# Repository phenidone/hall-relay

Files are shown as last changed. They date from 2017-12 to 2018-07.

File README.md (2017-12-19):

# hall-relay

This is a PCB design for a hall-effect sensor with normally-closed, high-current open-drain output.

The intended purpose is to directly control a low-voltage DC load, e.g. cupboard lighting
or it can be integrated with an alarm or building-management system as a door/window sensor.

The open-drain output is active when a magnetic field is not present, i.e. when the door is open and the magnet is away from this sensor.

## Power Supply

This relay will operate between 5V and 24V DC nominal; the absolute-maximum voltage rating is 28V.  It is not reverse-polarity protected.

It has an open-drain output capable of driving up to 1A into an inductive load (relay or solenoid)
or up to 2A into simple (LED tape) loads.

## Magnet

To shut off the relay, align a magnet pole with the OSHW (gear) logo on the non-component side of the board.

The sensor is omnipolar so it doesn't matter which way the magnet is installed.

## Installation

This sensor should be placed in a door frame with the non-component side of the board exposed to the moving item (door?) that
is to be detected.  Two screw-holes are provided for fixing, and these screws can double as magnetic latching/anchor points.

The PCB assembly must be potted in epoxy after assembly to protect it from moisture.

Connect a 5V-24V isolated plugpack to the + and - terminals.

Connect a DC load (expecting the same voltage as supplied by the plugpack) between the + and OD terminals

## License

This hardware design is (C) 2017 William Brodie-Tyrrell and is licensed under the CERN OHL; see cern_ohl_v_1_2.pdf

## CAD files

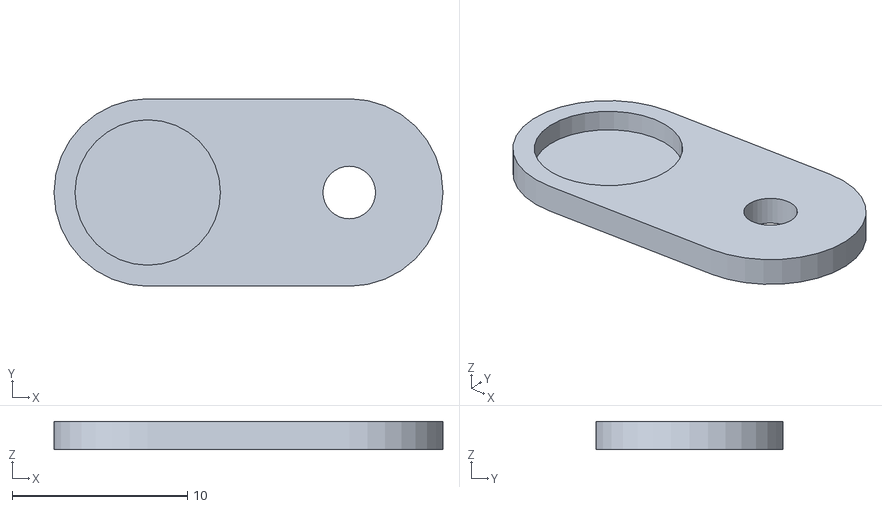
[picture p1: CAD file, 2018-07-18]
housing/magnet-flat.stl
22.2 x 10.7 x 1.60

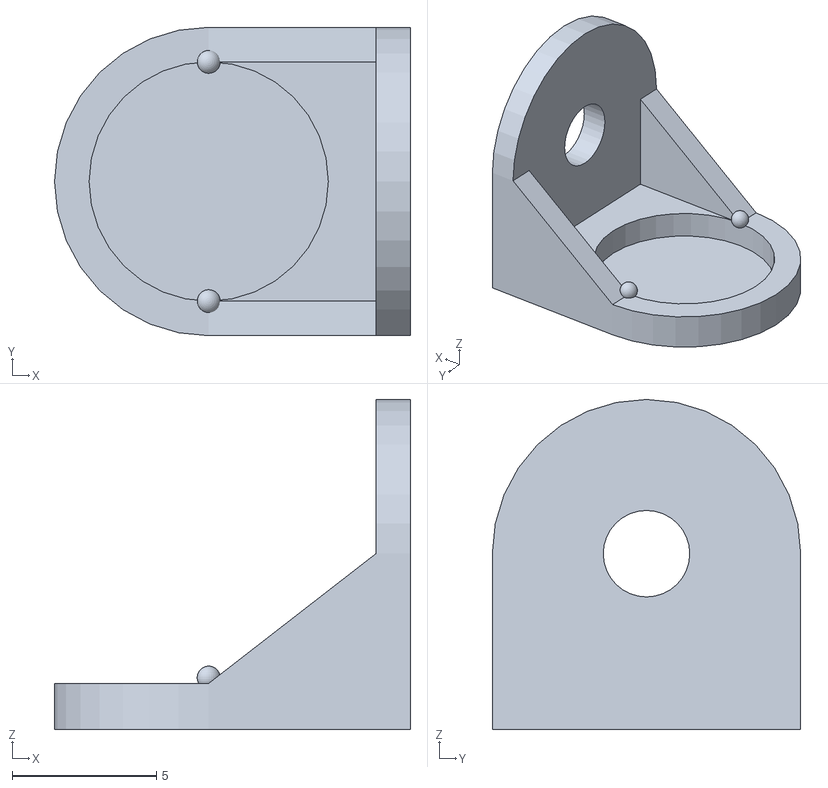
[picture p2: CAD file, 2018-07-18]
housing/magnet-90deg.stl
12.4 x 10.7 x 11.4

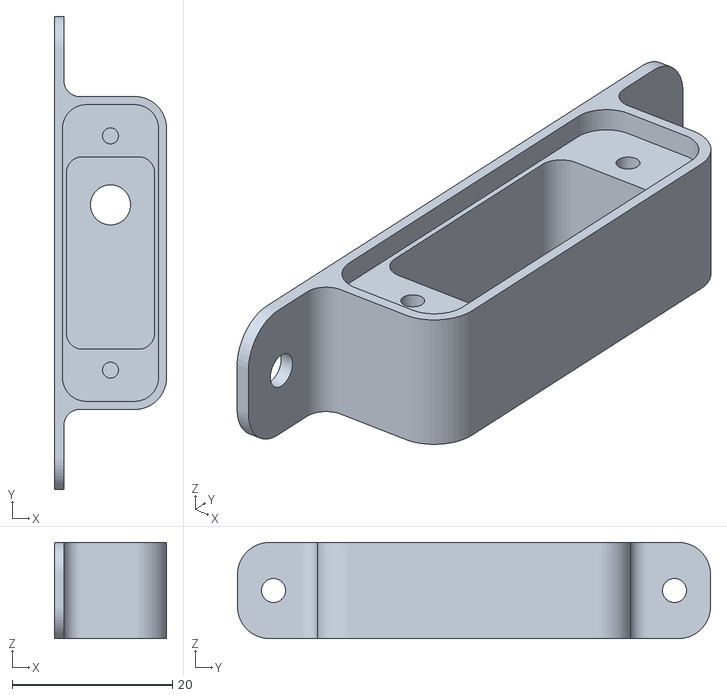
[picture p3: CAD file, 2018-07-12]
housing/hall-90deg.stl
14.0 x 59.0 x 12.0

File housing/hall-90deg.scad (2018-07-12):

// with thanks to HAD...
module cylinders(points, radius, height)
{
    for (p=points){
        translate(p) cylinder(r=radius, h=height, center=true);
    }
}

// box, rounded in 2 dimensions but flat top+bottom
// is centred
module round2box(size, radius)
{
    points=[ [-size[0]/2+radius, -size[1]/2+radius, 0],
             [-size[0]/2+radius, size[1]/2-radius, 0],
             [size[0]/2-radius, -size[1]/2+radius, 0],
             [size[0]/2-radius, size[1]/2-radius, 0]];
    
    hull() cylinders(points, radius, size[2]);
}

// bracket dimensions
epsilon=0.05;
pcbrad=3;
fillet=2;
wall=1;
tablen=10;
tabthick=1.2;
outerrad=pcbrad+wall;
pcb=[12, 37, 2];  // PCB space
clearance=[11, 24, 9];  // component-area
outer=[pcb[0]+2*wall, pcb[1]+2*wall, clearance[2]+3];  // casing size
tabs=[outer[2], outer[1]+2*tablen, outer[0]/2];
tabfillet=[outer[0], tablen+2*outerrad, outer[2]+1];
screwpilot=2;
screw=3;
screwspace=1.15*25.4;
cable=5;

$fn=50;
$fs=epsilon;

// assemble, upside-down for ease of FDM printing
rotate(a=[0, 180, 0]) difference()
{
    union()
    {
        // datum: centre of bottom face
        translate([0, 0, outer[2]/2])
            // the main casing
            round2box([outer[0], outer[1]+epsilon, outer[2]], outerrad);

        // side tabs - overly thick to make room for fillet
        translate([outer[0]/2-tabs[2]/2, 0, outer[2]/2]) rotate(a=[0, 90, 0])
            round2box(tabs, outerrad);
    }

    // space for the PCBA
    translate([0, 0, -epsilon])
    {
        // datum: bottom centre of the PCB
        
        // pcb space
        translate([0, 0, pcb[2]/2])
            round2box(pcb, pcbrad);

        // component-area clearance
        translate([0, 0, clearance[2]/2+pcb[2]-epsilon])
            // cube(clearance, true);
            round2box(clearance, fillet);
        
        // cable clearance
        translate([0, clearance[1]/4, outer[2]/2])
            cylinder(d=cable, h=outer[2]+1, center=true);
        
        // PCB-screw pilot holes
        translate([0, 0, outer[2]/2-1])
            cylinders([[0, screwspace/2, 0], [0, -screwspace/2, 0]], screwpilot/2, outer[2]);

        
    }

    // fillets from backs of end tabs
    translate([-tabthick, -(tabfillet[1]+outer[1])/2, tabfillet[2]/2-epsilon])
            round2box(tabfillet, fillet);
    translate([-tabthick, (tabfillet[1]+outer[1])/2, tabfillet[2]/2-epsilon])
            round2box(tabfillet, fillet);
    
    // screw clearance holes in tabs
    translate([outer[0]/2, 0, outer[2]/2]) rotate(a=[0, 90, 0])
        cylinders([[0, (outer[1]+tablen+1)/2, 0], [0, -(outer[1]+tablen+1)/2, 0]], screw/2, outer[0]/2);
}

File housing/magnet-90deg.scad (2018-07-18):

// a 90-degree bracket to hold a cylindrical magnet
// the magnet is on the INSIDE of the bracket, which helps with printing and also
// means it's not visible from the direction the magnet would normally be looked at from

// this version has tiny press-retaining tabs so no magnet glue is required.

mag_diam=8.3;
mag_thick=1.2;
mag_ctr=7;
tab_thick=1.2;
skin=0.4;
wall=tab_thick;
screw=3;
screw_ctr=4.5;
wall_ctr=screw_head;

// total width of the bracket
width=mag_diam+2*wall;

epsilon=1e-2;
$fn=32;

// flip part on its back for easy FDM printing
rotate(a=[0, -90, 0]) union() {

    // magnet-holding vertical thing
    rotate(a=[0, -90, 0]){
        difference(){
            union(){
                translate([mag_ctr, 0, 0]) cylinder(d=width, h=mag_thick+skin, center=false);
                translate([0, -width/2, 0]) cube([mag_ctr, width, mag_thick+skin], center=false);
            }

            translate([mag_ctr, 0, -epsilon]) cylinder(d=mag_diam, h=mag_thick, center=false);
        }
        
        // retaining tabs
        for(y=[mag_diam/2, -mag_diam/2]){
            translate([mag_ctr, y, 0]) {
                translate([0, 0, -0.2]) sphere(d=0.8);
                // rotate(a=[45, 0, 0]) cube(0.8, center=true);
            }
        }

    }

    // screw-down tab
    difference(){
        union(){
            translate([screw_ctr, 0, 0]) cylinder(d=width, h=tab_thick, center=false);
            translate([0, -width/2, 0]) cube([screw_ctr, width, tab_thick], center=false);
        }

        translate([screw_ctr, 0, -epsilon]) cylinder(d=screw, h=tab_thick+1, center=false);
    }
    
    // bracing
    for(y=[-width/2, width/2-wall]){
        hull(){
            translate([-1, y, tab_thick-1]) cube([screw_ctr+1, wall, 1], center=false);
            translate([-1, y, 1]) cube([1, wall, mag_ctr-1 /*+0.2*/], center=false);
        }
    }
}

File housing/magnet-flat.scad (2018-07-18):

// a flat bracket to hold a cylindrical magnet
// the magnet is on the INSIDE of the bracket, which
// means it's not visible from the direction the bracket would normally be looked at from

// there are optional tiny retaining tabs

mag_diam=8.3;
mag_thick=1.2;
mag_ctr=7;
skin=0.4;
wall=1.2;
screw=3;
screw_ctr=4.5;
tabs=false;

// total width of the bracket
width=mag_diam+2*wall;

epsilon=1e-2;
$fn=32;

// flip part on its back for easy FDM printing
rotate(a=[0, 180, 0]){
    difference(){
        hull(){
            translate([mag_ctr, 0, 0]) cylinder(d=width, h=mag_thick+skin, center=false);
            translate([-screw_ctr, 0, 0]) cylinder(d=width, h=mag_thick+skin, center=false);
        }

        // magnet hole
        translate([mag_ctr, 0, -epsilon]) cylinder(d=mag_diam, h=mag_thick, center=false);

        // screw hole
        translate([-screw_ctr, 0, -epsilon]) cylinder(d=screw, h=(mag_thick+skin+1), center=false);
    }

    if(tabs){
        // retaining tabs
        for(y=[mag_diam/2, -mag_diam/2]){
            translate([mag_ctr, y, 0]) {
                translate([0, 0, -0.2]) sphere(d=0.8);
            }
        }
    }
    
}

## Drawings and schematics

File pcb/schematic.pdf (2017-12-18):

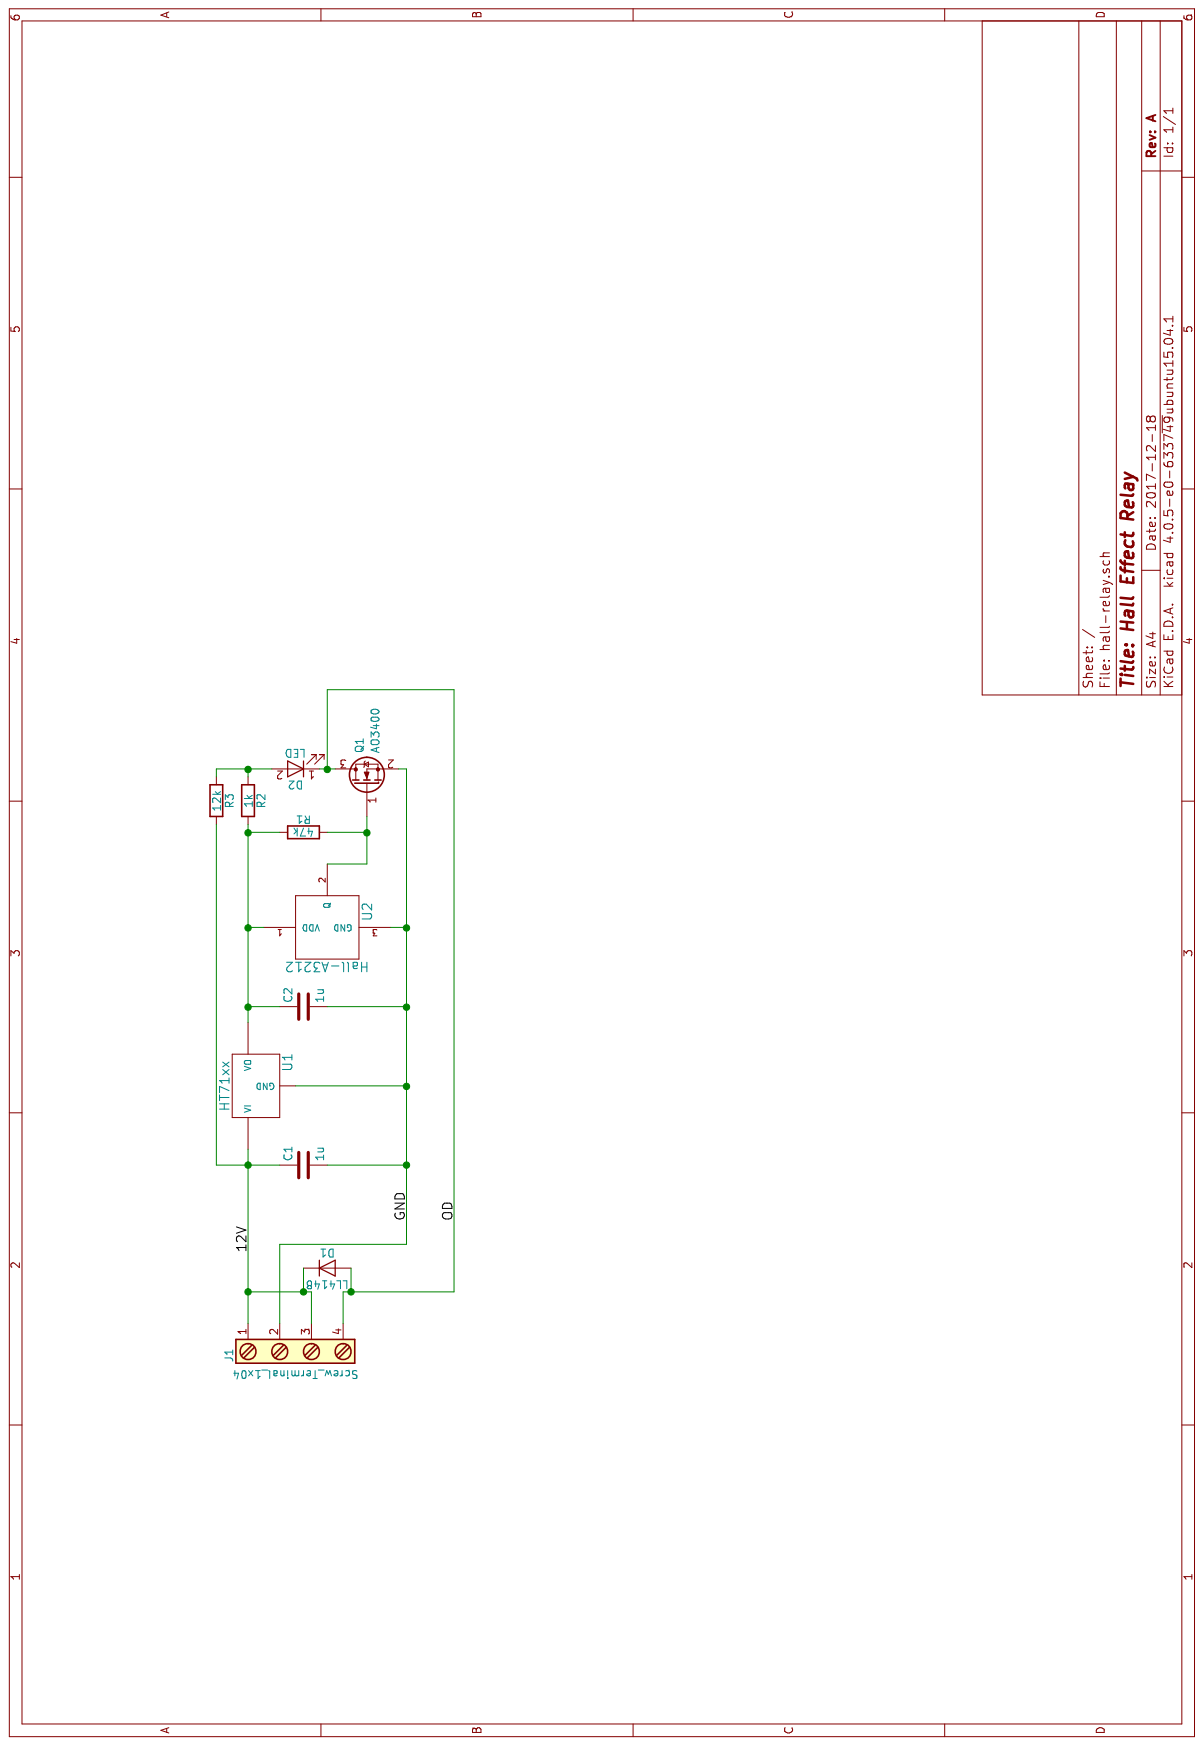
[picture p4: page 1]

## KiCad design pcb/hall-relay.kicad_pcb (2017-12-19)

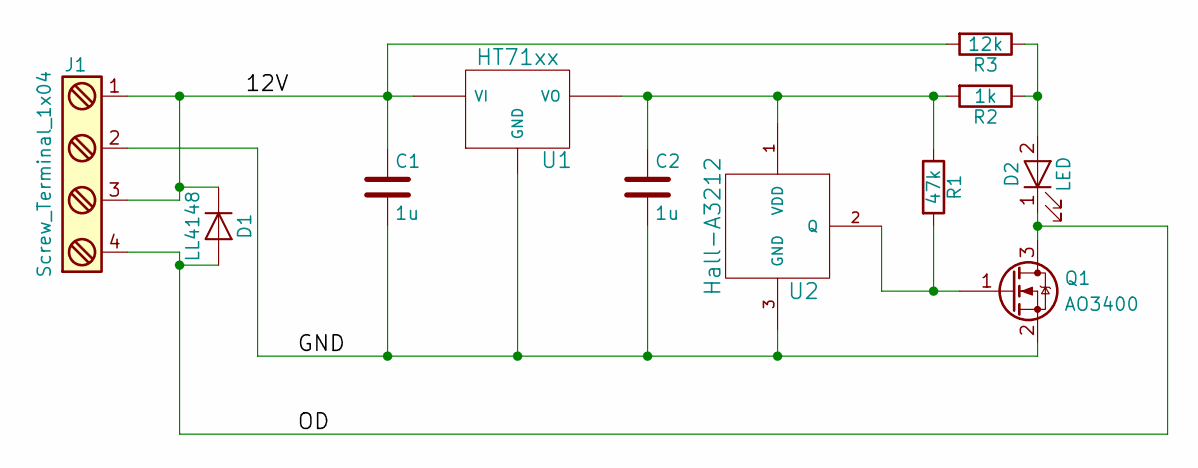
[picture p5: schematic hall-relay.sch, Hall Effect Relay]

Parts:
C1, C2: 1u; C_0805
D1: LL4148; D_MiniMELF
D2: LED; LED_0805
J1: Screw_Terminal_1x04; TerminalBlock_Phoenix_MPT-2.54mm_4pol
Q1: AO3400; SOT-23
R1: 47k; R_0805
R2: 1k; R_0805
R3: 12k; R_0805
U1: HT71xx; SOT-89-3
U2: Hall-A3212; SOT-23

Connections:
/12V: C1.1, D1.1 (K), J1.1, J1.3, R3.2, U1.2 (VI)
/GND: C1.2, C2.2, J1.2, Q1.2 (S), U1.1 (GND), U2.3 (GND)
/OD: D1.2 (A), D2.1 (K), J1.4, Q1.3 (D)
unnamed: C2.1, R1.1, R2.2, U1.3 (VO), U2.1 (VDD)
unnamed: D2.2 (A), R2.1, R3.1
unnamed: Q1.1 (G), R1.2, U2.2 (Q)

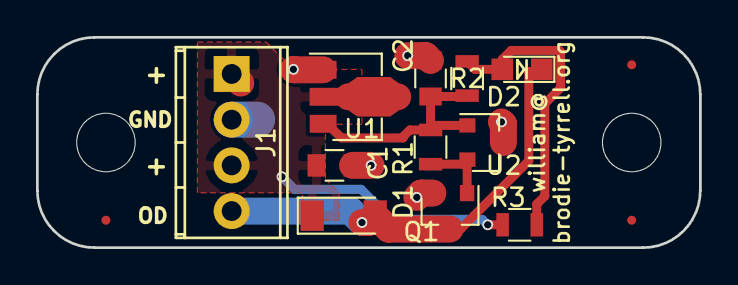
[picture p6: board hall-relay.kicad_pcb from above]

Board: 2 copper layers, 36.8 x 11.7 mm, 11 parts (0 on the bottom side), 6 nets.

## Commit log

2017-12-17 neatened schematic, added PDF
    [hall-relay.kicad_pcb, hall-relay.sch]
2017-12-18 added LED pullup option to unregulated; avoids LED reverse-breakdown problems
    [hall-relay-B.Cu.gbr, hall-relay-B.Mask.gbr, hall-relay-B.SilkS.gbr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]
2017-12-18 regenerated schematic pdf
2017-12-19 shortened board to fit panelisation
    [hall-relay-B.Cu.gbr, hall-relay-B.Mask.gbr, hall-relay-B.SilkS.gbr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]
2018-06-24 moved PCB design to subdirectory, drafted SCAD for a printable 90-deg mounting bracket
    [hall-90deg.scad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]
2018-06-24 added STL
    [hall-90deg.stl]
2018-07-12 made housing a bit shallower
    [hall-90deg.scad, hall-90deg.stl]
2018-07-18 added 90-degree magnet-mount (non-retained)
    [magnet-90deg.scad, magnet-90deg.stl]
2018-07-18 added tiny magnet-retaining tabs so no glue is required.
    [magnet-90deg.scad, magnet-90deg.stl]
2018-07-18 added flat magnet-retaining bracket.
    [magnet-flat.scad, magnet-flat.stl]
